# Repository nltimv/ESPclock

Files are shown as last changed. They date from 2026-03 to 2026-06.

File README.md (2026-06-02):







> **This is a fork of [telepath9/ESPclock](https://github.com/telepath9/ESPclock).**
> It includes additional features and fixes on top of the original project.
> See [CHANGES.md](CHANGES.md) for the full list of changes made in this fork.

Welcome to the page of my (W.I.P.) project called 



which is a smart clock that connects to a NTP server to get the current time. 
It uses a ESP8266 (Wemos D1 mini) or ESP32 (XIAO ESP32 C3).





<h2>📜 INSTRUCTIONS </h2>

1. Install VSCode or <b>VSCodium</b> (i prefer VSCodium because it basically is VSCode but <b>without</b> telemetry);

2. Install PlatformIO extension on VSCode/VSCodium;

3. Clone the repository and open the esp8266/tm1637_display folder in PlatformIO

4. From the PlatformIO extension, store the html page into the esp8266 flash memory in two steps:
	1. Platform -> Build filesystem image
	2. Platform -> Upload filesystem image

5. Now lets upload the C/C++ code. Again from the PlatformIO extension in VSCode/VSCodium, go to:
	1. General -> Build
	2. General -> Upload

6. Now let's connect PC or mobile to the ESPclock access point (SSID: `ESPclock-<DEVICE_ID>`, with the password: espclock

7. After connecting to the ESPclock's AP, open your browser and paste in the address bar: http://192.168.4.1/ (or `espclock-<DEVICE_ID>.local`).

8. From the web UI, first add your home network, and then choose your timezone. The IP of the device on your network will be shown. Connect back to your own network and enter the IP to configure the device.

9. And we're done! Hope that you liked my project! If you have any suggestions, let me know!

<h2>🔎 CENTRAL DEVICE FINDER WEB APP</h2>

This repository also includes a static web app to find a clock by `DEVICE_ID`
on the local network and open its control panel without remembering its IP.

Path: `device-finder/`

- UI: `device-finder/site/index.html`
- NGINX config: `device-finder/nginx/default.conf`
- Container image: `device-finder/Dockerfile`

Build and run:

```bash
cd device-finder
docker build -t espclock-device-finder .
docker run --rm -p 8080:80 espclock-device-finder
```

Then open: `http://<host-ip>:8080/`

Notes:
- The finder first tries `http://espclock-<DEVICE_ID>.local`, then can scan a
  user-provided `/24` subnet by querying `/uicheck`.
- Setup-mode deep links are supported with `http://192.168.4.1/` when connected
  to the device AP `ESPclock-<DEVICE_ID>`.
- If the finder page is hosted over HTTPS, browsers may block discovery requests
  to local HTTP device endpoints (mixed-content restriction).

<h2>📱 WEB UI </h2>
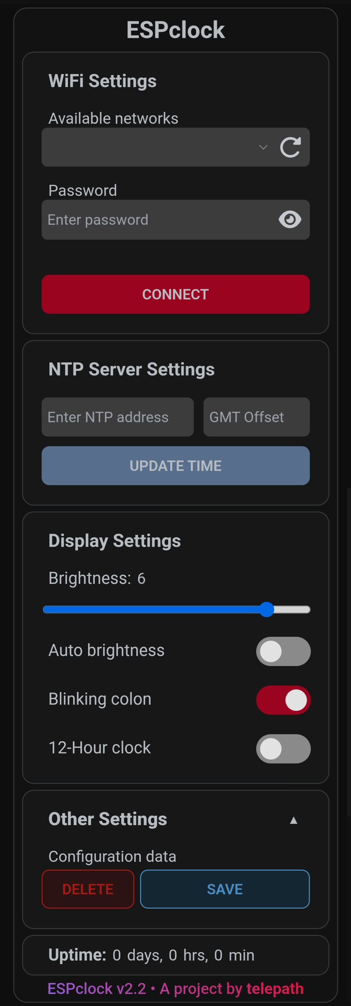
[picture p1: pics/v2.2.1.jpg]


<h2>🤖 CURRENT FEATURES</h2>

- [x] Asynchronous webserver
- [x] Automatic Wifi Scan</li>
- [x] Wifi and NTP server setup via web UI
- [x] Save/delete configuration (used to restore data after reboot)
- [x] Automatic Brightness mode
- [x] Blinking colon toggle
- [x] ESP32 port
- [x] Replace NTPclient.h with time.h library
- [x] ESPmDNS
- [x] 12-Hour clock mode
- [ ] Alarm clock mode with buzzer
- [x] Display Uptime in webUI
- [ ] Adding 1 or 2 buttons to the case
- [ ] ESPhome or Homeassistant integration
- [ ] HA support
- [x] TM1652 0.8" display support https://it.aliexpress.com/item/1005007337668399.html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
- [x] POSIX timezone string support (correct DST handling) *(fork)*
- [x] Setup mode: access point only active during initial setup *(fork)*
- [x] Automatic AP shutdown (~15 s grace period) after setup completes *(fork)*
- [x] `DEVICE_ID` compile-time macro — run multiple clocks on the same network without SSID/mDNS conflicts *(fork)*
- [x] WiFi scan sorted by signal strength with duplicate SSIDs removed *(fork)*
- [x] Clickable IP address and mDNS hostname shown in web UI after setup *(fork)*
- [x] ESP8266 web UI added (was missing from upstream) *(fork)*

<h2>🛒 PART LIST</h2>
<details>
<summary><b>TM1637 Display Version</b></summary>
<ul>
<li>XIAO ESP32 C3 or Wemos D1 MINI (mine is V3.0.0 clone)</li>
<li>TM1637 module https://it.aliexpress.com/item/1005001582129952.html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 </li>
<li>Dupont wires</li>
<li>DG308 7pins terminal block (for XIAO) OR DG308 8pins terminal block (for WEMOS): x2</li>
<li>Female 7pins header(for XIAO) OR Female 8pins header (for WEMOS): x2</li>
<li>7x3cm perfboard: x1</li>
<li>M2.5 screws: x10</li>
<li>M2.5 nuts: x2</li>
<li>Single row female 5pins header (for common GND): x1</li>
</ul>
</details>

<h2>🔌 BOARD WIRING</h2>
<details> 
<summary><b>XIAO ESP32 C3</b></summary>


</details>
<details> 
<summary><b>ESP8266 (Wemos D1 Mini 3.0.0)</b></summary> 



</details>

<h2>🪛 HOW TO ASSEMBLE ESPclock</h2>


<h2>🤝 CODE CONTRIBUTIONS</h2>
The original project is a personal project by telepath9, who does not accept pull requests upstream.
This fork welcomes issues and suggestions. Feel free to open an issue if you spot something or have an idea.

<h2>❤️ SUPPORT</h2>
If you liked the project and want to financially contribute, you can buy me a coffee! <br><br>



Support the original creator [here](https://github.com/telepath9/ESPclock?tab=readme-ov-file#%EF%B8%8F-support).

<h2>⚠️ TROUBLESHOOTING</h2>
There are (at the moment) two errors that can be displayed from the 7-segment display:
<ul>
<li>Err0 -> when "LittleFS.begin()" fails</li>
<li>Err1 -> when "index.html" doesn't exists in flash memory (user forgot to upload it)</li>
</ul>

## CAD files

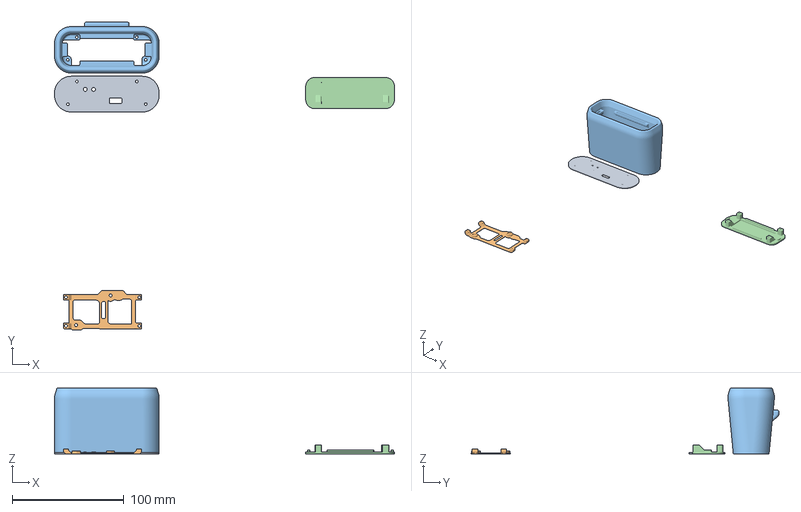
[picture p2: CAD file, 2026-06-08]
3d_models/bold_case/ESPClock.3mf
304.1 x 275.7 x 59.0 mm
NEW_Base_PCB.stl
BOLD_1.3.stl
tm_mask_v1.1 +0.2.stl

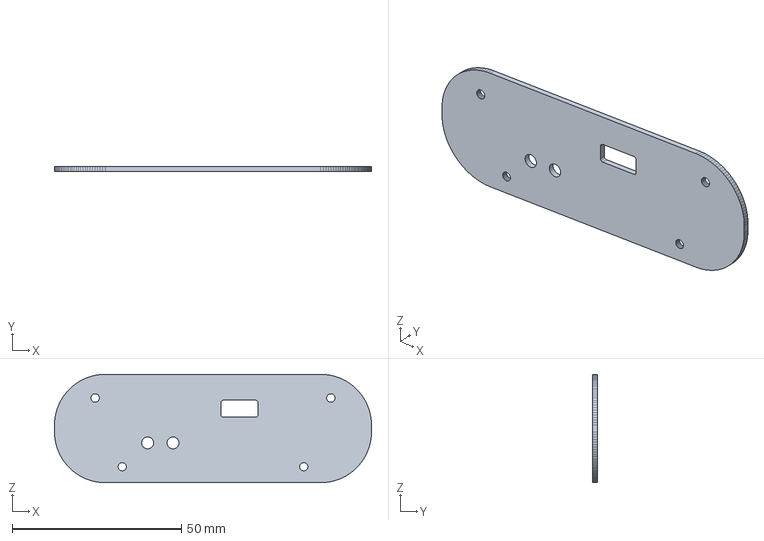
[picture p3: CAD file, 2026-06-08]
3d_models/bold_case/lid_BOLD.FCStd
93.6 x 1.50 x 32.0 mm

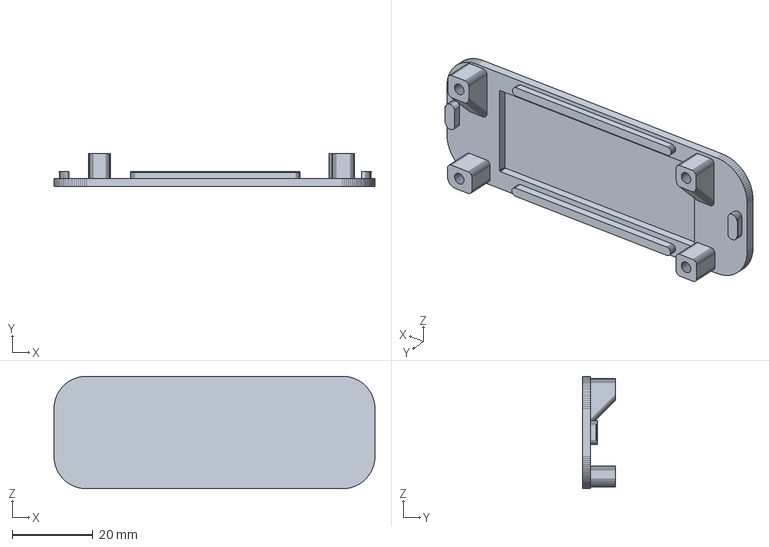
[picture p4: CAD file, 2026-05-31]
3d_models/bold_case/tm_mask_v1.1 +0.2.FCStd
79.4 x 8.20 x 27.8 mm

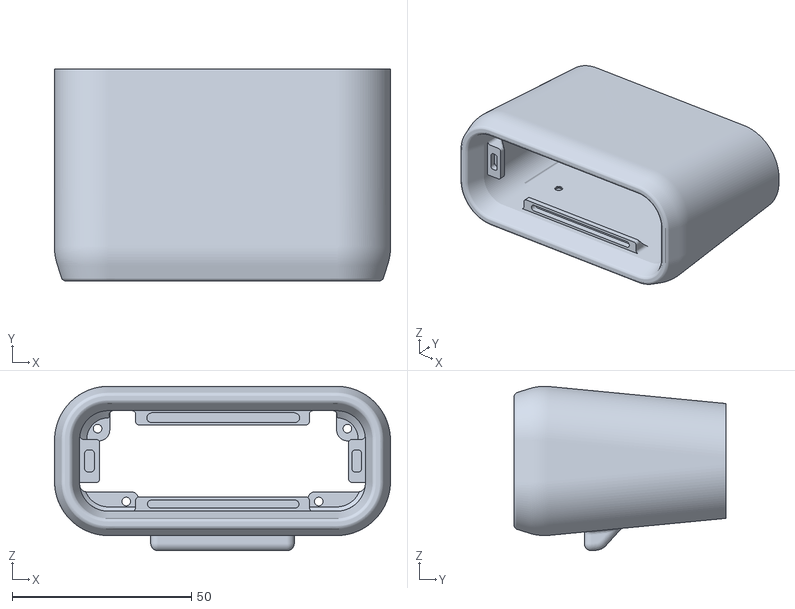
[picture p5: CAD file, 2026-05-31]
3d_models/bold_case/ALT_FILLET_case_BOLD_v1.2_SHELLed.stl
93.6 x 59.0 x 45.8

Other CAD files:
3d_models/bold_case/lid_BOLD.stl
3d_models/bold_case/tm_mask_v1.1 +0.2.stl

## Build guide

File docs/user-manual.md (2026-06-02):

---
classoption: oneside
---

\begin{titlepage}
\centering
\vspace*{3cm}

{\fontsize{28}{34}\selectfont\bfseries ESPclock\par}

\vspace{0.8cm}

{\fontsize{16}{20}\selectfont User Manual\par}

\vspace{0.5cm}

{\large Setup \& Usage Guide\par}

\vspace{2cm}

\begin{tikzpicture}
  \draw[line width=1.5pt, rounded corners=6pt] (0,0) rectangle (3,1.6);
  \node[font=\fontsize{22}{26}\selectfont\ttfamily\bfseries] at (1.5,0.8) {12:00};
\end{tikzpicture}

\vfill

{\normalsize ESPclock Project by telepath9 and nltimv\par}
{\small Wi-Fi Enabled Desk Clock\par}

\vspace{1cm}
\etocsettocstyle{}{}
\etocsetstyle{part}{}{}{\normalsize\etocname\dotfill\etocpage\par\vspace{0.1em}}{}
\setcounter{tocdepth}{-1}
\tableofcontents

\end{titlepage}

\refstepcounter{part}
\addcontentsline{toc}{part}{English}

\begin{center}
{\fontsize{20}{24}\selectfont\bfseries English\par}
\end{center}

\etocsettocstyle{\section*{Table of Contents}}{}
\etocsettocdepth{1}
\localtableofcontents
\newpage
# Welcome

Thank you for choosing the **ESPclock** — a Wi-Fi-enabled desk clock built on
the ESP microcontroller platform. This manual will guide you through setting up
your clock step by step.

The ESPclock can work in two modes:

- **Online mode** — connects to your home Wi-Fi and automatically gets the
  correct time from the internet.
- **Offline mode** — works without Wi-Fi; you set the time manually using two
  buttons on the device.

The clock has two buttons, labeled **S** (Setup) and **A** (Action). On the
bottom of the device you will find a sticker with a **QR code** and the
clock's web address — you can scan it later to access the settings page.

# What's in the Box

Before you start, make sure you have:

- The ESPclock device (fully assembled)
- A USB cable for power
- A phone, tablet, or computer with Wi-Fi

# Powering On

1. Plug the USB cable into the clock and connect it to a USB power source
   (wall adapter, power bank, or computer).
2. The display will light up. If this is the first time you are using the
   clock, it will start in **offline mode** and show `00:00`.

# Online Setup (Recommended)

Online mode is the easiest way to use your clock. It connects to your Wi-Fi
network and keeps the time accurate automatically.

## Step 1: Connect to the Clock's Wi-Fi

When the clock starts in offline mode, it creates its own temporary Wi-Fi
network (a "hotspot") for 15 minutes.

1. On your phone or computer, open the **Wi-Fi settings**.
2. Look for a network named **ESPclock-XXXXXX** (where XXXXXX is a unique
   code for your clock).
3. Connect to it using the password: **`espclock`**

> **Tip:** The clock's hotspot is only active for 15 minutes after powering
> on. If you miss it, simply unplug the clock and plug it back in.

## Step 2: Open the Setup Page

Once connected to the clock's Wi-Fi:

1. Open a web browser (Chrome, Safari, Firefox, etc.).
2. Go to: **http://192.168.4.1**
3. The ESPclock setup page will appear.

## Step 3: Connect to Your Home Wi-Fi

On the setup page you will see a **Wi-Fi Settings** section:

1. The **Available networks** dropdown shows all Wi-Fi networks the clock can
   detect. Select your home network.
   - If you don't see your network, tap the **Refresh** button.
2. Enter your Wi-Fi **password** in the password field.
   - You can tap the eye icon to show/hide the password.
3. Tap **CONNECT**.

> **If connection fails:** Double-check your Wi-Fi password and try again.

## Step 4: Choose Your Timezone

After connecting to Wi-Fi, the setup page shows a **Timezone** section:

1. Select your **Region** (e.g., Europe, America, Asia).
2. Select your **City** (e.g., Amsterdam, New York, Tokyo).
3. Tap **SAVE & FINISH**.

The clock will now sync with an internet time server and display the correct
time for your timezone. The setup is complete!

## Step 5: Reconnect to Your Home Wi-Fi

After the setup finishes, the clock turns off its hotspot.

1. On your phone or computer, reconnect to your **home Wi-Fi** network.
2. You can now access the clock's settings at any time by scanning the
   **QR code** on the bottom of the clock, or by typing the address printed
   on the sticker into your browser.

# Offline Setup (No Internet)

If you don't have Wi-Fi or prefer not to connect the clock to the internet,
you can set the time manually using the two buttons on the device.

## Entering Time Edit Mode

1. Make sure the clock is **not** connected to Wi-Fi (offline mode).
2. **Press and hold** the **S button** (Setup) for about 2 seconds.
3. The display will start blinking — you are now in time edit mode.

## Setting the Time

Once in time edit mode, you will go through three steps:

### 1. Choose 12-Hour or 24-Hour Format

- The display will show either **12h** or **24h**.
- **Press** the **A button** to switch between formats.
- **Press** the **S button** to confirm and move on.

### 2. Set the Hour

- The hour digits will blink.
- **Press** the **A button** to increase the hour.
  The value will cycle from 0 through 23 (or 1 through 12 in 12-hour mode)
  and wrap around.
- **Press** the **S button** to confirm and move to minutes.

### 3. Set the Minutes

- The minute digits will blink.
- **Press** the **A button** to increase the minutes.
  The value will cycle from 0 through 59 and wrap around.
- **Press** the **S button** to confirm.

The clock will now start keeping time from the values you set.

# Changing Settings (Online Mode)

When the clock is connected to your Wi-Fi, you can change its settings using
any web browser on the same network.

1. Scan the **QR code** on the bottom of the clock, or type the address
   printed on the sticker into your browser.
2. The settings page will appear.

## Time Settings

- **NTP Server** — The internet time server. The default (`pool.ntp.org`)
  works well for most people. You usually don't need to change this.
- **Timezone** — Select your Region and City, then tap **UPDATE TIME**.

## Display Settings

- **Brightness** — Drag the slider (0 = dimmest, 7 = brightest).
- **Auto brightness** — When turned on, the clock automatically adjusts
  brightness based on the time of day:
  - Night (12 AM – 9 AM): Very dim
  - Day (9 AM – 5 PM): Bright
  - Evening (5 PM – 8 PM): Medium
  - Late evening (8 PM – 12 AM): Dim
- **Blinking colon** — Toggle the blinking dots between the hours and minutes.
- **12-Hour clock** — Toggle between 12-hour (1:00 – 12:59) and 24-hour
  (0:00 – 23:59) display.

## Saving Settings

- Tap **UPDATE** to store your settings permanently. They will be remembered
  even after a power outage.
- If you ever want to start fresh, tap **DELETE** to erase all saved settings
  and return the clock to offline mode.

# Resetting the Clock

If you want to erase all settings and start over (for example, to connect to
a different Wi-Fi network):

1. **Press and hold both buttons (S and A)** at the same time.
2. **Continue holding** until the display flashes the digits `0:00` on and off (at about
   **10 seconds**). This confirms the reset is complete.
3. You can now **release both buttons**. The clock will restart in offline
   you can set it up from scratch.

> You can also reset the clock from the web interface by tapping **DELETE**
> in the Configuration section.

# Troubleshooting

## The display shows "Err0"

The clock's internal storage has a problem. Try unplugging and replugging the
clock. If the error persists, the device may need to be reflashed.

## The display shows "Err1"

The web interface files are missing from the clock's storage. The device needs
to have its filesystem re-uploaded. Contact the person who built the clock.

## I can't find the clock's Wi-Fi hotspot

The hotspot is only active for **15 minutes** after the clock is powered on.
Unplug the clock, wait a few seconds, and plug it back in. The hotspot will
appear again.

## The clock shows the wrong time

1. Open the clock's web interface.
2. Check that the correct **Timezone** (Region and City) is selected.
3. Tap **UPDATE TIME** to re-sync.

## I forgot the clock's address

Scan the **QR code** on the bottom of the clock, or type the address printed
on the sticker into your browser. The address is also shown in the Wi-Fi
hotspot name (ESPclock-**XXXXXX** → **http://espclock-XXXXXX.local**).

## The Wi-Fi password was wrong

Double-check your password and tap **CONNECT** again. Make sure you're
entering the password for your home Wi-Fi — not the clock's hotspot password.

# Quick Reference

| What you want to do | How to do it |
|---|---|
| First-time setup | Connect to ESPclock-XXXXXX Wi-Fi → open 192.168.4.1 → follow steps |
| Change settings | Scan QR code on bottom of clock |
| Set time manually | Hold S button 2 sec → use A button to set |
| Reset the clock | Hold both buttons (S + A) for 10 seconds |
| Hotspot password | `espclock` |

---

*ESPclock — an open-source project licensed under GPL-3.0, available at https://www.gnu.org/licenses/gpl-3.0.en.html *

*Visit https://github.com/nltimv for more information and the source code of the clock.*

\newpage

\refstepcounter{part}
\addcontentsline{toc}{part}{Nederlands}

\begin{center}
{\fontsize{20}{24}\selectfont\bfseries Nederlands\par}
\end{center}

\bigskip

\etocsettocstyle{\section*{Inhoudsopgave}}{}
\etocsettocdepth{1}
\localtableofcontents
\newpage

\setcounter{section}{0}

# Welkom

Bedankt voor het kiezen van de **ESPclock** — een bureauklok met
Wi-Fi-verbinding, gebouwd op het ESP-microcontrollerplatform. Deze
handleiding begeleidt u stap voor stap bij het instellen van uw klok.

De ESPclock heeft twee modi:

- **Online modus** — maakt verbinding met uw Wi-Fi-netwerk en haalt
  automatisch de juiste tijd op via internet.
- **Offline modus** — werkt zonder Wi-Fi; u stelt de tijd handmatig in
  met de twee knoppen op het apparaat.

De klok heeft twee knoppen, gelabeld **S** (Setup) en **A** (Action). Op
de onderkant van het apparaat vindt u een sticker met een **QR-code** en
het webadres van de klok — scan deze later om de instellingenpagina te
openen.

# Inhoud van de verpakking

Controleer voordat u begint of u het volgende heeft:

- Het ESPclock-apparaat (volledig gemonteerd)
- Een USB-kabel voor de stroomvoorziening
- Een telefoon, tablet of computer met Wi-Fi

# Inschakelen

1. Sluit de USB-kabel aan op de klok en verbind deze met een
   USB-stroombron (adapter, powerbank of computer).
2. Het display licht op. Als u de klok voor het eerst gebruikt, start
   deze in **offline modus** en toont `00:00`.

# Online instellen (aanbevolen)

Online modus is de eenvoudigste manier om uw klok te gebruiken. De klok
maakt verbinding met uw Wi-Fi-netwerk en houdt de tijd automatisch
nauwkeurig.

## Stap 1: Verbind met het Wi-Fi van de klok

Wanneer de klok in offline modus opstart, maakt deze een eigen tijdelijk
Wi-Fi-netwerk (een "hotspot") aan, dat 15 minuten actief blijft.

1. Open de **Wi-Fi-instellingen** op uw telefoon of computer.
2. Zoek een netwerk met de naam **ESPclock-XXXXXX** (waarbij XXXXXX een
   unieke code is voor uw klok).
3. Maak verbinding met het wachtwoord: **`espclock`**

> **Tip:** De hotspot van de klok is slechts 15 minuten actief na het
> inschakelen. Als u deze mist, trek de stekker eruit en sluit de klok
> opnieuw aan.

## Stap 2: Open de instellingenpagina

Nadat u verbonden bent met het Wi-Fi van de klok:

1. Open een webbrowser (Chrome, Safari, Firefox, etc.).
2. Ga naar: **http://192.168.4.1**
3. De instellingenpagina van de ESPclock verschijnt.

## Stap 3: Verbind met uw eigen Wi-Fi-netwerk

Op de instellingenpagina ziet u het onderdeel **Wi-Fi Settings**:

1. Het menu **Available networks** toont alle Wi-Fi-netwerken die de klok
   kan detecteren. Selecteer uw thuisnetwerk.
   - Ziet u uw netwerk niet? Tik op **Refresh**.
2. Voer uw Wi-Fi-**wachtwoord** in.
   - U kunt op het oogpictogram tikken om het wachtwoord te
     tonen/verbergen.
3. Tik op **CONNECT**.

> **Als de verbinding mislukt:** controleer uw Wi-Fi-wachtwoord en
> probeer het opnieuw.

## Stap 4: Kies uw tijdzone

Na het verbinden met Wi-Fi toont de instellingenpagina het onderdeel
**Timezone**:

1. Selecteer uw **Region** (bijv. Europe, America, Asia).
2. Selecteer uw **City** (bijv. Amsterdam, New York, Tokyo).
3. Tik op **SAVE & FINISH**.

De klok synchroniseert nu met een internettijdserver en toont de juiste
tijd voor uw tijdzone. De installatie is voltooid!

## Stap 5: Maak opnieuw verbinding met uw eigen Wi-Fi

Na het afronden van de installatie schakelt de klok de hotspot uit.

1. Verbind uw telefoon of computer opnieuw met uw **eigen
   Wi-Fi-netwerk**.
2. U kunt de instellingen van de klok op elk moment openen door de
   **QR-code** op de onderkant van de klok te scannen, of door het adres
   op de sticker in uw browser in te voeren.

# Offline instellen (zonder internet)

Als u geen Wi-Fi heeft of de klok liever niet met internet verbindt,
kunt u de tijd handmatig instellen met de twee knoppen op het apparaat.

## Tijdinstelmodus activeren

1. Zorg ervoor dat de klok **niet** verbonden is met Wi-Fi (offline
   modus).
2. **Houd** de **S-knop** (Setup) ongeveer 2 seconden **ingedrukt**.
3. Het display begint te knipperen — u bent nu in de tijdinstelmodus.

## De tijd instellen

In de tijdinstelmodus doorloopt u drie stappen:

### 1. Kies 12-uurs- of 24-uursnotatie

- Het display toont **12h** of **24h**.
- **Druk** op de **A-knop** om de instelling aan te passen.
- **Druk** op de **S-knop** om te bevestigen en verder te gaan.

### 2. Stel het uur in

- De urcijfers knipperen.
- **Druk** op de **A-knop** om het uur te verhogen. De waarde
  loopt van 0 tot 23 (of 1 tot 12 in 12-uursmodus) en begint daarna
  opnieuw.
- **Druk** op de **A-knop** om te bevestigen en naar de minuten te
  gaan.

### 3. Stel de minuten in

- De minutencijfers knipperen.
- **Druk** op de **A-knop** ingedrukt om de minuten te verhogen. De waarde
  loopt van 0 tot 59 en begint daarna opnieuw.
- **Druk** op de **A-knop** om te bevestigen.

De klok begint nu de tijd bij te houden vanaf de ingestelde waarden.

# Instellingen wijzigen (online modus)

Wanneer de klok verbonden is met uw Wi-Fi, kunt u de instellingen
wijzigen via een webbrowser op hetzelfde netwerk.

1. Scan de **QR-code** op de onderkant van de klok, of voer het adres op
   de sticker in uw browser in.
2. De instellingenpagina verschijnt.

## Tijdinstellingen

- **NTP Server** — De internettijdserver. De standaardwaarde
  (`pool.ntp.org`) werkt goed voor de meeste gebruikers. Dit hoeft u
  meestal niet te wijzigen.
- **Timezone** — Selecteer uw Region en City en tik op **UPDATE TIME**.

## Beeldscherminstellingen

- **Brightness** — Versleep de schuifbalk (0 = dimst, 7 = helderst).
- **Auto brightness** — Wanneer ingeschakeld, past de klok de
  helderheid automatisch aan op basis van het tijdstip:
  - Nacht (00:00 – 09:00): Zeer dim
  - Dag (09:00 – 17:00): Helder
  - Avond (17:00 – 20:00): Gemiddeld
  - Late avond (20:00 – 00:00): Dim
- **Blinking colon** — Schakel de knipperende dubbele punt tussen de
  uren en minuten in of uit.
- **12-Hour clock** — Schakel tussen 12-uursnotatie (1:00 – 12:59) en
  24-uursnotatie (0:00 – 23:59).

## Instellingen opslaan

- Tik op **UPDATE** om uw instellingen permanent op te slaan. Ze blijven
  bewaard, ook na een stroomuitval.
- Als u opnieuw wilt beginnen, tik dan op **DELETE** om alle opgeslagen
  instellingen te wissen en de klok terug te zetten naar offline modus.

# De klok resetten

Als u alle instellingen wilt wissen en opnieuw wilt beginnen
(bijvoorbeeld om verbinding te maken met een ander Wi-Fi-netwerk):

1. **Houd beide knoppen (S en A)** tegelijkertijd ingedrukt.
2. **Blijf vasthouden** totdat het display de cijfers `0:00` aan en uit flitst (na
   ongeveer **10 seconden**). Dit bevestigt dat de reset is voltooid.
3. U kunt nu **beide knoppen loslaten**. De klok start opnieuw op in
   offline modus en de hotspot wordt weer 15 minuten beschikbaar, zodat
   u de klok opnieuw kunt instellen.

> U kunt de klok ook resetten via de webinterface door op **DELETE** te
> tikken in het onderdeel Configuration.

# Probleemoplossing

## Het display toont "Err0"

Het interne geheugen van de klok heeft een probleem. Probeer de klok los
te koppelen en opnieuw aan te sluiten. Als de fout aanhoudt, moet het
apparaat mogelijk opnieuw worden geflasht.

## Het display toont "Err1"

De bestanden voor de webinterface ontbreken in het geheugen van de klok.
Het bestandssysteem moet opnieuw worden geüpload. Neem contact op met de
persoon die de klok heeft gebouwd.

## Ik kan de Wi-Fi-hotspot van de klok niet vinden

De hotspot is slechts **15 minuten** actief na het inschakelen van de
klok. Trek de stekker eruit, wacht een paar seconden en sluit de klok
opnieuw aan. De hotspot verschijnt dan weer.

## De klok toont de verkeerde tijd

1. Open de webinterface van de klok.
2. Controleer of de juiste **Timezone** (Region en City) is geselecteerd.
3. Tik op **UPDATE TIME** om opnieuw te synchroniseren.

## Ik ben het adres van de klok vergeten

Scan de **QR-code** op de onderkant van de klok, of voer het adres op de
sticker in uw browser in. Het adres is ook af te leiden uit de naam van
de hotspot (ESPclock-**XXXXXX** → **http://espclock-XXXXXX.local**).

## Het Wi-Fi-wachtwoord was onjuist

Controleer uw wachtwoord en tik opnieuw op **CONNECT**. Zorg ervoor dat
u het wachtwoord van uw thuisnetwerk invoert — niet het wachtwoord van
de hotspot van de klok.

# Naslagkaart

| Wat u wilt doen | Hoe u het doet |
|---|---|
| Eerste installatie | Verbind met ESPclock-XXXXXX Wi-Fi → open 192.168.4.1 → volg de stappen |
| Instellingen wijzigen | Scan de QR-code op de onderkant van de klok |
| Tijd handmatig instellen | Houd S-knop 2 sec. ingedrukt → gebruik A-knop |
| Klok resetten | Houd beide knoppen (S + A) 10 seconden ingedrukt |
| Hotspot-wachtwoord | `espclock` |

---

*ESPclock — een opensourceproject onder de GPL-3.0-licentie, te raadplegen via https://www.gnu.org/licenses/gpl-3.0.en.html *

*Bezoek https://github.com/nltimv/ESPClock voor meer informatie en de broncode van de klok.*

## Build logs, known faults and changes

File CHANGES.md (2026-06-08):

# Changes from upstream

This project is a fork of [telepath9/ESPclock](https://github.com/telepath9/ESPclock),
which is licensed under the [GNU General Public License v3.0 (GPL-3.0)](LICENSE).

The following changes have been made in this fork by
[nltimv](https://github.com/nltimv):

---

## 2026-06-08

### Wi-Fi reconnect behavior (`src/espclock.cpp`, `lib/espclock_common/src/wifi_manager.cpp`, `lib/espclock_common/src/display.cpp`)
- Changed Wi-Fi retry indicator to remove `trY` text and show progressive dashes per attempt (`-`, `--`, `---`, `----`).
- Added non-blocking reconnect scheduling at a fixed 1-minute cadence when saved Wi-Fi credentials fail at boot.
- Added automatic reconnect scheduling at the same 1-minute cadence after an already-connected device loses Wi-Fi.

### Online time sync reliability (`src/espclock.cpp`)
- Added an online-mode NTP scheduler that re-requests NTP synchronization at least once every 24 hours while connected.
- Added bounded retry backoff (5 minutes up to 60 minutes) when the device has not yet acquired valid NTP time.
- Added build-time override flag `NTP_RESYNC_INTERVAL_S` and a dedicated PlatformIO test environment that sets it to 300 seconds for quick validation.

---

## 2026-05-20

### User manual (`docs/`)
- Added a user manual covering online (Wi-Fi/NTP) and offline (manual buttons) setup, clock settings, reset procedure, and troubleshooting.
- Created a Docker-based build pipeline (`docs/scripts/`) that converts the Markdown source into a foldable A4 landscape booklet PDF using pandoc, pdflatex, and pdfjam.

---

## 2026-05-19

### Display and time setup behavior (`src/espclock.cpp`, `lib/espclock_common/src/display_api.h`, `lib/espclock_common/src/display.cpp`)
- Removed online/offline state-indicator rendering from the clock face; time display now consistently uses the classic blinking center colon behavior.
- Simplified display and edit-mode rendering by removing date-editing screens and making only the active time field blink during manual setup.
- Updated button-driven setup UX: long-press setup enters time editing immediately, action-button hold cycles values continuously, and 12h/24h selection is shown as `12h`/`24h`.
- Added clearer dual-button reset flow with continuous `88:88` hold feedback, offline-mode reset, and clock reset to `00:00`.
- Reset the internal one-second timer anchor whenever the clock time is changed in offline/manual flows, so timing restarts cleanly from `:00`.

### First-time setup flow reliability (`src/espclock.cpp`, `lib/espclock_common/src/web_server.cpp`)
- Kept AP setup available through Wi-Fi connection until timezone submission, then switched to STA-only mode.
- Preserved setup-complete feedback by delaying final AP shutdown briefly so completion pages can render reliably.

---

## 2026-05-18

### Device identity defaults (`lib/espclock_common/src/wifi_manager.*`, `src/espclock.cpp`, `platformio.ini`)
- Changed the default `DEVICE_ID` behavior to generate a deterministic ID from the hardware MAC address, so reflashing the same board keeps the same identity without manual build flags.
- Reduced the default MAC-derived `DEVICE_ID` to the last 6 hexadecimal characters for shorter AP/mDNS names.
- Kept `DEVICE_ID` build-flag override support for users who still want custom IDs.

### Offline/online operation and button control (`src/espclock.cpp`, `lib/espclock_common/src/wifi_manager.*`, `lib/espclock_common/src/web_server.cpp`, `platformio.ini`)
- Repurposed setup/normal behavior into offline/online modes, with offline AP availability limited to a 15-minute boot window and default clock start at 00:00.
- Added two debounced GPIO push buttons for local time setup (hours, minutes, 12/24h) and dual-button reset back to offline mode.
- Added reset flow feedback on dual-button hold and aligned config-reset handling to consistently return the device to offline onboarding mode.

### Web UI wording (`data/index.html`)
- Updated setup-related labels/messages to use clearer offline/online language for non-technical users.

### 3D model improvements
- Removed touch sensor cutout for bold case
- Created an extra latch in the bold case to keep the TM shield in place
- Add 3MF with all the parts

---

## 2026-04-12

### Setup and discovery user experience (`device-finder/site/index.html`)
- Improved the setup and discovery user experience by unifying first-time setup and daily access into a single deep-link flow with simpler screens and clearer guidance.
- Added automatic local-network discovery (mDNS first, then subnet scan) and setup-mode detection so users can reach the device with fewer manual steps.

### Captive portal and setup reliability (`lib/espclock_common/src/wifi_manager.*`, `lib/espclock_common/src/web_server.cpp`, `src/espclock.cpp`)
- Removed the firmware captive-portal DNS redirect and shifted setup handoff to the finder flow to avoid interruptions on mobile platforms.
- Adjusted `/uicheck` CORS behavior to support hosted finder deployments while keeping the endpoint read-only.

### Timezone architecture and web UI (`lib/espclock_common/src/tz_lookup.*`, `lib/espclock_common/src/ntp.h`, `lib/espclock_common/src/web_server.cpp`, `lib/espclock_common/src/wifi_manager.cpp`, `data/index.html`, `data/tz.json`)
- Reworked timezone handling to use IANA names end-to-end, with device-side POSIX lookup from `tz.json`.
- Replaced large inline timezone data in the web UI with a data-driven region/city selector sourced from `/tz.json`.
- Updated and corrected timezone mappings against authoritative tzdata sources to improve timezone accuracy.

### Firmware structure and build layout (`platformio.ini`, `firmware/`, `lib/espclock_common/`, `src/espclock.cpp`)
- Consolidated firmware variants into a unified project structure and shared display abstraction to reduce duplication and simplify maintenance.
- Moved PlatformIO configuration to the repository root for consistent root-level builds.
- Fixed Wi-Fi mode initialization to prevent unintended default AP behavior in normal operation.

---

## 2026-04-09

### Shared codebase refactor (`lib/espclock_common/`, `esp32/`, `esp8266/tm1637_display/src/`)
- Introduced a shared firmware library and display abstraction, and split large source files into clearer modules.
- Aligned ESP32 behavior with the ESP8266 feature set for setup flow, timezone handling, configuration schema, and API responses.

---

## 2026-04-08

### Setup completion user experience (`esp32/tm1637_display`, `esp32/tm1652_display`, `esp8266/tm1637_display`)
- Added direct IP and mDNS links after timezone setup so users can open the device UI faster.

---

## 2026-04-06

### Firmware setup, networking, and time config (`esp8266/tm1637_display/src/espclock8266.cpp`, `esp32/tm1637_display/src/espclock32.cpp`, `esp32/tm1652_display/src/espclock32.cpp`)
- Added setup-mode improvements (conditional AP behavior, automatic AP shutdown, and safer config handling) to improve first-time setup and reconnection reliability.
- Improved network identity and discovery support with `DEVICE_ID`-based naming and richer setup/status API responses.
- Upgraded time configuration to POSIX timezone support and expanded timezone setup flow.

### Web UI and project scaffolding (`esp32/data/index.html`, `esp8266/tm1637_display/data/index.html`, `esp8266/tm1637_display/`)
- Expanded the web UI setup flow to match firmware changes and added an ESP8266 web UI where upstream had none.
- Added missing ESP8266 project scaffolding files needed for local development and builds.

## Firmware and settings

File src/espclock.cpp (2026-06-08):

// ESPclock - Unified firmware main entry point
// This file is part of the ESPclock project fork by nltimv.
// Originally written by telepath9 (https://github.com/telepath9/ESPclock)
// Licensed under the GNU General Public License v3.0 (GPL-3.0)
// SPDX-License-Identifier: GPL-3.0-or-later
//
// This file has been modified by nltimv (https://github.com/nltimv).

// This single source file covers all three build environments defined in
// platformio.ini (ESP8266 + TM1637, ESP32 + TM1637, ESP32 + TM1652).
// Platform-specific behaviour is isolated to two #ifdef ESP8266 guards.

#include <Arduino.h>
#include <time.h>
#include <sys/time.h>

#ifdef ESP8266
#include <ESP8266WiFi.h>
#include <ESP8266mDNS.h>
#else  // ESP32
#include <WiFi.h>
#include <ESPmDNS.h>
#endif

#include <LittleFS.h>

#include "display.h"
#include "wifi_manager.h"
#include "web_server.h"
#include "ntp.h"
#include "json_config.h"

// ── NTP / time globals ─────────────────────────────────────────────────────
const char *ntp_addr      = "pool.ntp.org";
const char *tz_iana       = "UTC";
const char *tz_posix      = "UTC0";
bool        start_NtpClient = false;
struct tm   timeinfo;

#ifndef SETUP_BUTTON_PIN
#ifdef ESP8266
#define SETUP_BUTTON_PIN 14
#else
#define SETUP_BUTTON_PIN 4
#endif
#endif

#ifndef ACTION_BUTTON_PIN
#ifdef ESP8266
#define ACTION_BUTTON_PIN 12
#else
#define ACTION_BUTTON_PIN 5
#endif
#endif

#ifndef BUTTON_ACTIVE_STATE
#define BUTTON_ACTIVE_STATE LOW
#endif

#ifndef BUTTON_PIN_MODE
#define BUTTON_PIN_MODE INPUT_PULLUP
#endif

#ifndef NTP_RESYNC_INTERVAL_S
#define NTP_RESYNC_INTERVAL_S (24UL * 60UL * 60UL)
#endif

static const unsigned long AP_OFFLINE_WINDOW_MS  = 15UL * 60UL * 1000UL;
static const unsigned long AP_SETUP_CONFIRM_WINDOW_MS = 5UL * 1000UL;
static const unsigned long BUTTON_DEBOUNCE_MS    = 35UL;
static const unsigned long BUTTON_SHORT_PRESS_MS = 80UL;
static const unsigned long BUTTON_LONG_PRESS_MS  = 1200UL;
static const unsigned long BUTTON_REPEAT_MS      = 300UL;
static const unsigned long EDIT_FLASH_MS         = 450UL;
static const unsigned long RESET_HINT_MS         = 5000UL;
static const unsigned long RESET_HOLD_MS         = 10000UL;
static const unsigned long WIFI_RETRY_INTERVAL_MS = 60UL * 1000UL;
static const unsigned long NTP_RETRY_MIN_MS      = 5UL * 60UL * 1000UL;
static const unsigned long NTP_RETRY_MAX_MS      = 60UL * 60UL * 1000UL;
static const time_t        NTP_MIN_VALID_EPOCH   = 1735689600;  // 2025-01-01T00:00:00Z
static const uint32_t      NTP_DAILY_RESYNC_S    = (uint32_t)NTP_RESYNC_INTERVAL_S;

enum class EditField : uint8_t {
    NONE = 0,
    TWELVE_24,
    HOUR,
    MINUTE
};

static bool          in_time_setup           = false;
static EditField     edit_field              = EditField::NONE;
static tm            edit_time               = {};
static bool          show_edit_value         = true;
static unsigned long edit_flash_toggle_at    = 0;

struct ButtonState {
    bool          raw_state = false;
    bool          debounced_state = false;
    unsigned long raw_changed_ms = 0;
    unsigned long pressed_at_ms = 0;
    bool          short_released = false;
    bool          long_released = false;
    bool          long_pressed = false;
    bool          long_press_fired = false;
    unsigned long long_press_next_ms = 0;
};

static ButtonState   setup_button;
static ButtonState   action_button;
static bool          both_held_active    = false;
static unsigned long both_held_since_ms  = 0;
static bool          reset_hint_active   = false;
static bool          reset_done          = false;
static bool          combo_in_progress   = false;
static bool          ntp_scheduler_initialized  = false;
static time_t        ntp_last_valid_epoch       = 0;
static time_t        ntp_last_daily_request     = 0;
static unsigned long ntp_last_attempt_ms        = 0;
static unsigned long ntp_retry_ms               = NTP_RETRY_MIN_MS;
static unsigned long wifi_last_retry_ms         = 0;

static void setClockFromTm(const tm &src) {
    tm copy = src;
    copy.tm_isdst = -1;
    time_t epoch = mktime(&copy);
    if (epoch < 0) return;
    timeval tv = {epoch, 0};
    settimeofday(&tv, nullptr);
    myTimerReset();
}

static void setDefaultClockTime() {
    tm t = {};
    t.tm_year = 124;  // 2024
    t.tm_mon  = 0;    // Jan
    t.tm_mday = 1;
    t.tm_hour = 0;
    t.tm_min  = 0;
    t.tm_sec  = 0;
    setClockFromTm(t);
}

static void loadCurrentTime(tm &dst) {
    time_t now = time(nullptr);
    localtime_r(&now, &dst);
}

static void requestNtpResync(const __FlashStringHelper *reason) {
    if (!connected || !start_NtpClient) return;

    configTzTime(tz_posix, ntp_addr);
    ntp_last_attempt_ms = millis();

    Serial.print(F("NTP resync requested: "));
    Serial.println(reason);
}

static void initNtpSchedulerIfNeeded() {
    if (ntp_scheduler_initialized || !connected || !start_NtpClient) return;

    ntp_scheduler_initialized = true;
    ntp_retry_ms             = NTP_RETRY_MIN_MS;
    ntp_last_attempt_ms      = millis();

    time_t now_epoch = time(nullptr);
    if (now_epoch >= NTP_MIN_VALID_EPOCH) {
        ntp_last_valid_epoch   = now_epoch;
        ntp_last_daily_request = now_epoch;
        Serial.println(F("NTP scheduler initialized with valid time"));
    } else {
        ntp_last_valid_epoch   = 0;
        ntp_last_daily_request = 0;
        Serial.println(F("NTP scheduler initialized; waiting for first sync"));
    }
}

static void handleNtpScheduler() {
    if (!connected || !start_NtpClient) {
        ntp_scheduler_initialized = false;
        ntp_last_valid_epoch      = 0;
        ntp_last_daily_request    = 0;
        ntp_last_attempt_ms       = 0;
        ntp_retry_ms              = NTP_RETRY_MIN_MS;
        return;
    }

    initNtpSchedulerIfNeeded();

    time_t now_epoch = time(nullptr);
    if (now_epoch >= NTP_MIN_VALID_EPOCH) {
        if (ntp_last_valid_epoch == 0) {
            Serial.println(F("NTP valid time acquired"));
        }
        ntp_last_valid_epoch = now_epoch;
        ntp_retry_ms         = NTP_RETRY_MIN_MS;

        if (ntp_last_daily_request == 0 ||
            (uint32_t)(now_epoch - ntp_last_daily_request) >= NTP_DAILY_RESYNC_S) {
            requestNtpResync(F("daily"));
            ntp_last_daily_request = now_epoch;
        }
        return;
    }

    if (ntp_last_attempt_ms == 0 || (millis() - ntp_last_attempt_ms) >= ntp_retry_ms) {
        requestNtpResync(F("retry"));
        ntp_retry_ms = (ntp_retry_ms >= (NTP_RETRY_MAX_MS / 2UL))
            ? NTP_RETRY_MAX_MS
            : (ntp_retry_ms * 2UL);
    }
}

static void showResetConfirmFeedback() {
    for (uint8_t i = 0; i < 2; ++i) {
        displayClear();
        delay(140);
        displayShowTime(0, 0, true, false);
        delay(140);
    }
}

static void startTimeSetup() {
    loadCurrentTime(edit_time);
    in_time_setup        = true;
    edit_field           = EditField::TWELVE_24;
    show_edit_value      = true;
    edit_flash_toggle_at = millis();
}

static void advanceTimeSetupField() {
    switch (edit_field) {
        case EditField::TWELVE_24: edit_field = EditField::HOUR;      break;
        case EditField::HOUR:      edit_field = EditField::MINUTE;    break;
        case EditField::MINUTE:
            setClockFromTm(edit_time);
            in_time_setup = false;
            edit_field    = EditField::NONE;
            return;
        default:
            return;
    }
    show_edit_value      = true;
    edit_flash_toggle_at = millis();
}

static void cycleCurrentValue() {
    switch (edit_field) {
        case EditField::HOUR:
            edit_time.tm_hour = (edit_time.tm_hour + 1) % 24;
            break;
        case EditField::MINUTE:
            edit_time.tm_min = (edit_time.tm_min + 1) % 60;
            break;
        case EditField::TWELVE_24:
            twelve = !twelve;
            break;
        default:
            break;
    }
    show_edit_value      = true;
    edit_flash_toggle_at = millis();
}

static void renderEditScreen() {
    if ((millis() - edit_flash_toggle_at) >= EDIT_FLASH_MS) {
        show_edit_value      = !show_edit_value;
        edit_flash_toggle_at = millis();
    }

    switch (edit_field) {
        case EditField::TWELVE_24:
            if (show_edit_value) {
                displayShowHourMode(twelve);
            } else {
                displayClear();
            }
            break;
        case EditField::HOUR:
            displayShowTimePartial(edit_time.tm_hour, edit_time.tm_min, true, twelve,
                                   show_edit_value, true);
            break;
        case EditField::MINUTE:
            displayShowTimePartial(edit_time.tm_hour, edit_time.tm_min, true, twelve,
                                   true, show_edit_value);
            break;
        default:
            displayShowTime(timeinfo.tm_hour, timeinfo.tm_min, true, twelve);
            break;
    }
}

static void updateButton(ButtonState &button, uint8_t pin) {
    bool pressed = (digitalRead(pin) == BUTTON_ACTIVE_STATE);
    unsigned long now = millis();

    button.short_released = false;
    button.long_released  = false;
    button.long_pressed   = false;

    if (pressed != button.raw_state) {
        button.raw_state = pressed;
        button.raw_changed_ms = now;
    }

    if ((now - button.raw_changed_ms) < BUTTON_DEBOUNCE_MS) {
        return;
    }

    if (button.debounced_state != button.raw_state) {
        button.debounced_state = button.raw_state;
        if (button.debounced_state) {
            button.pressed_at_ms    = now;
            button.long_press_fired = false;
        } else {
            unsigned long held = now - button.pressed_at_ms;
            if (held >= BUTTON_LONG_PRESS_MS) {
                button.long_released = true;
            } else if (held >= BUTTON_SHORT_PRESS_MS) {
                button.short_released = true;
            }
        }
    }

    // Fire long_pressed while the button is held past the long-press threshold,
    // then auto-repeat every BUTTON_REPEAT_MS.
    if (button.debounced_state) {
        unsigned long held = now - button.pressed_at_ms;
        if (held >= BUTTON_LONG_PRESS_MS) {
            if (!button.long_press_fired) {
                button.long_pressed          = true;
                button.long_press_fired      = true;
                button.long_press_next_ms    = now + BUTTON_REPEAT_MS;
            } else if (now >= button.long_press_next_ms) {
                button.long_pressed       = true;
                button.long_press_next_ms = now + BUTTON_REPEAT_MS;
            }
        }
    }
}

static void handleButtonInput() {
    updateButton(setup_button, SETUP_BUTTON_PIN);
    updateButton(action_button, ACTION_BUTTON_PIN);

    unsigned long now = millis();
    bool both_held = setup_button.debounced_state && action_button.debounced_state;

    if (both_held && !both_held_active) {
        both_held_active   = true;
        both_held_since_ms = now;
        reset_hint_active  = false;
        reset_done         = false;
        combo_in_progress  = true;
    }

    if (!both_held) {
        both_held_active = false;
        reset_hint_active = false;
        if (!setup_button.debounced_state && !action_button.debounced_state) {
            combo_in_progress = false;
        }
    }

    if (both_held_active) {
        unsigned long held = now - both_held_since_ms;
        reset_hint_active = (held >= RESET_HINT_MS && held < RESET_HOLD_MS && !reset_done);
        if (held >= RESET_HOLD_MS && !reset_done) {
            switchToOfflineMode(true);
            setDefaultClockTime();
            showResetConfirmFeedback();
            reset_done = true;
            reset_hint_active = false;
        }
    }

    if (!combo_in_progress) {
        // setup_mode=true means offline/local-setup mode; block manual time edits
        // once the device is in online mode and syncing time from the network.
        if (setup_mode && setup_button.long_pressed && !in_time_setup) {
            startTimeSetup();
        } else if (setup_button.short_released && in_time_setup) {
            advanceTimeSetupField();
        }

        if (in_time_setup && (action_button.short_released || action_button.long_pressed)) {
            cycleCurrentValue();
        }
    }
}

// ── setup() ───────────────────────────────────────────────────────────────
void setup() {
    Serial.begin(115200);
    pinMode(SETUP_BUTTON_PIN, BUTTON_PIN_MODE);
    pinMode(ACTION_BUTTON_PIN, BUTTON_PIN_MODE);

    displayInit();
    setDefaultClockTime();

    // Mount the filesystem (Err0 = mount failure)
    if (!LittleFS.begin()) {
        displayShowError(0);
        delay(10000);
        return;
    }

    // Verify the web UI is present (Err1 = missing index.html)
    if (!LittleFS.exists("/index.html")) {
        displayShowError(1);
        delay(10000);
        return;
    }

    // Attempt to restore a previously saved configuration
    checkConfig();

    // If restore failed with saved credentials, defer retries to loop() cadence.
    if (!connected && creds_available) {
        wifi_last_retry_ms = millis();
    }

    // Offline mode keeps AP available temporarily after boot.
    WiFi.mode(connected ? WIFI_STA : WIFI_AP_STA);
    WiFi.setAutoReconnect(true);

    initDeviceIdentity();
    initMDNS();
    delay(100);

    // Scan for nearby networks when not already connected
    if (WiFi.status() != WL_CONNECTED) {
        wifiScan();
    }

    // Start AP window only in offline mode.
    if (!connected) {
        WiFi.softAP(esp_ssid, esp_password, false, 2);
        ap_shutdown_start   = millis();
        ap_shutdown_pending = true;
    }

    setupRoutes();
}

// ── loop() ────────────────────────────────────────────────────────────────
void loop() {
#ifdef ESP8266
    MDNS.update();   // ESP8266 requires periodic mDNS polling; ESP32 does not
#endif

    // Shut down AP after the offline-mode boot window.
    // setup_mode flips to false in /setup_timezone before we start the final
    // AP shutdown timer, so false here means the short post-confirmation grace
    // period rather than the initial offline onboarding window.
    const unsigned long ap_shutdown_window_ms =
        setup_mode ? AP_OFFLINE_WINDOW_MS : AP_SETUP_CONFIRM_WINDOW_MS;
    if (ap_shutdown_pending && (millis() - ap_shutdown_start) >= ap_shutdown_window_ms) {
        WiFi.mode(WIFI_STA);
        ap_shutdown_pending = false;
    }

    // Perform a deferred WiFi rescan when requested by /scan or /refresh
    if (newScan) {
        wifiScan();
        newScan = false;
    }

    handleButtonInput();

    // ── Clock display ──────────────────────────────────────────────────────
    loadCurrentTime(timeinfo);
    handleNtpScheduler();

    if (myTimer(1000)) {
        // Auto-brightness: adjust at transition hours
        if (br_auto) {
            switch (timeinfo.tm_hour) {
                case 0:  brightness = 0; displaySetBrightness(0); break;
                case 9:  brightness = 6; displaySetBrightness(6); break;
                case 17: brightness = 3; displaySetBrightness(3); break;
                case 20: brightness = 2; displaySetBrightness(2); break;
            }
        }

        if (!in_time_setup) {
            colon = !colon;
        }
    }

    if (reset_hint_active) {
        displayShowTime(88, 88, true, false);
    } else if (in_time_setup) {
        renderEditScreen();
    } else {
        displayShowTime(timeinfo.tm_hour, timeinfo.tm_min, colon, twelve);
    }

    // ── WiFi connection ────────────────────────────────────────────────────
    wl_status_t wifi_status = WiFi.status();
    if (connected && wifi_status != WL_CONNECTED) {
        connected          = false;
        attempts           = 0;
        wifi_last_retry_ms = millis();
        Serial.println(F("WiFi connection lost; retrying every minute"));
    }

    if (!connected && creds_available) {
        displayAnim();

        if (wifi_last_retry_ms == 0 || (millis() - wifi_last_retry_ms) >= WIFI_RETRY_INTERVAL_MS) {
            wifi_last_retry_ms = millis();
            ++attempts;
            displayShowAttempt(attempts);
            Serial.print(F("WiFi reconnect attempt #"));
            Serial.println(attempts);
            WiFi.begin(ssid, password);
        }

        if (WiFi.status() == WL_CONNECTED) {
            bool was_setup_mode = setup_mode;
            connected          = true;
            setup_mode         = false;
            attempts           = 0;
            wifi_last_retry_ms = 0;
            initMDNS();

            // First-time setup: auto-save credentials and defaults;
            // NTP and AP shutdown are deferred to /setup_timezone.
            if (was_setup_mode && !LittleFS.exists("/config.json")) {
                JsonDocument config;
                config[F("ssid")]    = ssid;
                config[F("pw")]      = password;
                config[F("ntp_ad")]  = ntp_addr;
                config[F("tz")]      = tz_iana;
                config[F("br_auto")] = br_auto;
                config[F("br")]      = brightness;
                config[F("blink")]   = blink;
                config[F("twelve")]  = twelve;
                config.shrinkToFit();
                File fc = LittleFS.open("/config.json", "w+");
                serializeJsonPretty(config, fc);
                fc.close();
            }
        }
    }
}

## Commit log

2026-04-08 Add unique 4-char device ID to ESP8266 AP SSID and mDNS name derived from chip ID
    Agent-Logs-Url: https://github.com/nltimv/ESPclock/sessions/0fe39b8a-156c-4cfa-88f7-767f20df2dad
2026-04-08 Replace runtime chip ID generation with compile-time DEVICE_ID constant
    Agent-Logs-Url: https://github.com/nltimv/ESPclock/sessions/80fca335-2a8a-4ddc-8c4c-22bf7aa34ede
2026-04-09 refactor: merge esp8266+esp32 code into shared library; add display abstraction
    Agent-Logs-Url: https://github.com/nltimv/ESPclock/sessions/8390d1d6-34e1-4448-a0b5-dea06ec5d5ab
2026-04-12 refactor: unify display drivers + collapse to single platformio.ini with multi-env
    Agent-Logs-Url: https://github.com/nltimv/ESPclock/sessions/b4bd125c-335f-4551-8fbd-d9531acf816e
2026-04-12 feat: add central device finder web app and firmware CORS support
    Agent-Logs-Url: https://github.com/nltimv/ESPclock/sessions/209c2e72-4c54-49fe-bfcd-2d22da96f945
2026-04-12 docs: document device finder app and changelog entry
    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
2026-04-12 fix: tighten origin parsing and finder input validation
    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
2026-04-12 fix: use wildcard CORS on /uicheck so public-hosted finder app can reach device
    Agent-Logs-Url: https://github.com/nltimv/ESPclock/sessions/0fd85439-a040-40b4-9c2b-f858c659933e
2026-04-12 Guided troubleshooting on the device finder
2026-05-18 feat: generate deterministic device id from hardware MAC
    Agent-Logs-Url: https://github.com/nltimv/ESPclock/sessions/662b7725-acf5-4450-af45-7c8d30904a1e
2026-05-18 feat: shorten default MAC-based device id to 6 chars
    Agent-Logs-Url: https://github.com/nltimv/ESPclock/sessions/7dbf8f7a-cc97-4d6b-bd07-cc116a913fc3
2026-05-18 Switch from touch input to two debounced GPIO buttons
    Agent-Logs-Url: https://github.com/nltimv/ESPclock/sessions/d9a78b3e-68de-414d-bab4-00cc0f96d8e7
2026-05-18 3D model improvements
    - Removed touch sensor cutout for bold case
    - Created an extra latch in the bold case to keep the TM shield in place
    [ALT_FILLET_case_BOLD_v1.2_SHELLed.stl, ESPClock.3mf, lid_BOLD.FCStd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]
2026-05-19 Remove date stuff, fix per-field blinking, add dual-button reset
    Agent-Logs-Url: https://github.com/nltimv/ESPclock/sessions/e2d00e33-0089-4d7f-9a00-87ad67534266
    [espclock.cpp]
2026-05-19 Fire cycleCurrentValue while action button held (long-press + auto-repeat)
    Agent-Logs-Url: https://github.com/nltimv/ESPclock/sessions/2fbf4a4b-6769-453d-98f2-8afbdea3f9c3
2026-05-19 Fix time-setup flashing behavior and 12h/24h display text
    Agent-Logs-Url: https://github.com/nltimv/ESPclock/sessions/25810340-8279-4299-8bef-b5bfa431d3bb
    [espclock.cpp]
2026-05-19 Improve reset hold feedback and reset clock to 00:00
    Agent-Logs-Url: https://github.com/nltimv/ESPclock/sessions/e1453984-4989-4cb0-ae9a-72fc0f834969
    [espclock.cpp]
2026-05-19 Keep AP available until timezone selection in setup flow
    Agent-Logs-Url: https://github.com/nltimv/ESPclock/sessions/4a67dc85-5eb8-44c5-acff-4e9cf48c6285
2026-05-19 Reset internal timer anchor on manual offline time set
    Agent-Logs-Url: https://github.com/nltimv/ESPclock/sessions/dc2fff56-c85f-4f18-a2ad-34f8968528e5
    [espclock.cpp]
2026-05-19 Initialize timer anchor on first use
    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
2026-05-20 Add rear lid button labels
    [ESPClock.3mf]
2026-05-31 Fix symmetry issue
    [ALT_FILLET_case_BOLD_v1.2_SHELLed.stl, ESPClock.3mf, tm_mask_v1.1 +0.2.FCStd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]
2026-06-04 Combine TM mask again
    [ESPClock.3mf]
2026-06-08 Make button holes smaller
    [ESPClock.3mf, lid_BOLD.FCStd, lid_BOLD.stl]
2026-06-08 Name centered
    [ESPClock.3mf]
2026-06-08 Update case STL
    [ESPClock.3mf]
